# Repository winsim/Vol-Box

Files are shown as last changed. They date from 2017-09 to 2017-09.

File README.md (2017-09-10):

# **Vol-Box**
> A fairly simple project to create a 'USB Volume Control Box' using an Arduino Pro Micro 5v clone and AutoHotKey scripts. As well as integrating my Logitech X-240's original remote controller PCB and the bass control knob from the back of the sub box (such a horrid deisgn..) into the same enclosure as the Arduino.

###### _The Plan:_ 
 centralize ALL audio controls into one small(ish) space on my desk. Including:
   * Main volume control for Logitech X-240 speakers
   * Bass volume control for Logitech X-240 sub woofer
   * Main volume control and mute for computer via USB (done using NicoHood's HID library)
   * Google Chrome volume control and mute via USB (done using AutoHotkey Scripts)
   * Customizable game volume control and mute via USB (done using AutoHotkey Scripts)
   * 3x LEDs to show muted states of rotary encoders
   * Push button to change audio output/source (done using SoundSwitch)
###### _Why:_
   * the lightweight, always in the way or always falling off the back of my desk, often unreachable remote control for my Logitech X-240 speakers really doesn't fit at all into my computer setup and is often pushed off to the back of my desk behind the monitors and the control for the bass is located on the back of the sub box, which is also often pushed to the back of my desk making it very, very difficult to adjust the bass
   * also being as I watch a lot of Netflix and am often forced into changing the volume of whatever I'm watching via the slider given with the player, again this is a hassle.. wouldn't it be great just to have a knob to adjust the volume of Google Chrome within the volume mixer? I think it would! 
   * another problem I'm often faced with is adjusting the volume of fullscreened games.. this can be such a headache! The solution.. a knob to adjust the volume of whatever game (will have a short setup process due to having to change scripts around to your needs) I'm playing at the time within the volume mixer! 
   * sometimes you just have to adjust the master volume within the volume mixer.. soooo.. yet again, ANOTHER KNOB! Plus there's left over pins to play with! 
###### _How:_
   * Finish me! 

### _Overall Schematic:_

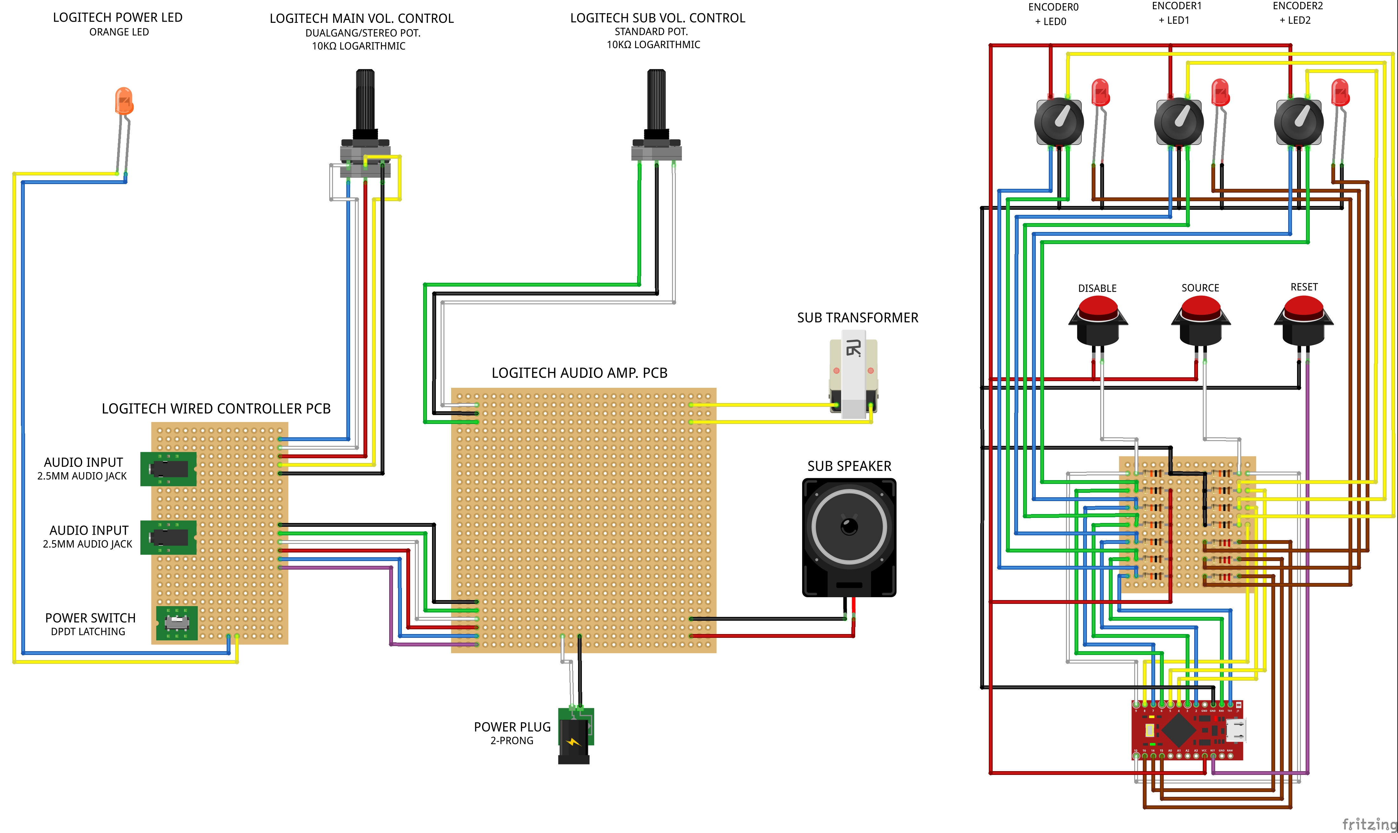
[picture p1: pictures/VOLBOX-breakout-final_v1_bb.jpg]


##### _Part One - Logitech X-240 Rework -_ 
###### _Step One -_ 
  * Remove PCB from inside of sub box
  * Desolder original potentiometer (bass control)
  * Solder 3x 18g wires in place of original potentiometer, secure with hot glue (I ended up using a computer PSU power cable with the                                                                                     ends cut off)
  * Feed wire through back of box and put the PCB back in place
###### _Step Two -_ 
  * Remove PCB from inside of the remote control
  * Desolder original sidewheel potentiometer (speaker volume) **BE CAREFUL! YOU MUST REMEMBER WHICH PINS WENT WHERE!**
  * Desolder original power LED
  * Solder 5x 24g wires in place of original potentiometer, secure with hot glue
  * Solder 2x 24g wires in place of original LED, secure with hot glue
  * Resecure original hot glue joints as they weren't secured very well
  * Cut 2x slots in the bottom of the enclosure to feed the PCB wires through
###### _Step Three -_
  * Drill appropriate holes in front of enclosure 
  * Mount PCB standoffs to controller board and secure to inside of enclosure with hot glue
  * Solder the other ends the 5x 24g wire to a dual-gang (stereo) potentiometer, jump the ground pins together **BE CAREFUL! THE PINOUT                                                                       ON THE BOARD IS REVERSED DUE TO CCW ROTATION TO TURN VOLUME UP!**
  * Solder the other ends of the 2x 24g wire to an orange panel-mount LED
  * Solder the other end of the new cable coming from the back of the sub box to a 10k Ω LOG potentiometer
  * Secure potentiometers and LED to front of enclosure
  * Close up and test out! 
  
###### _Schematic -_

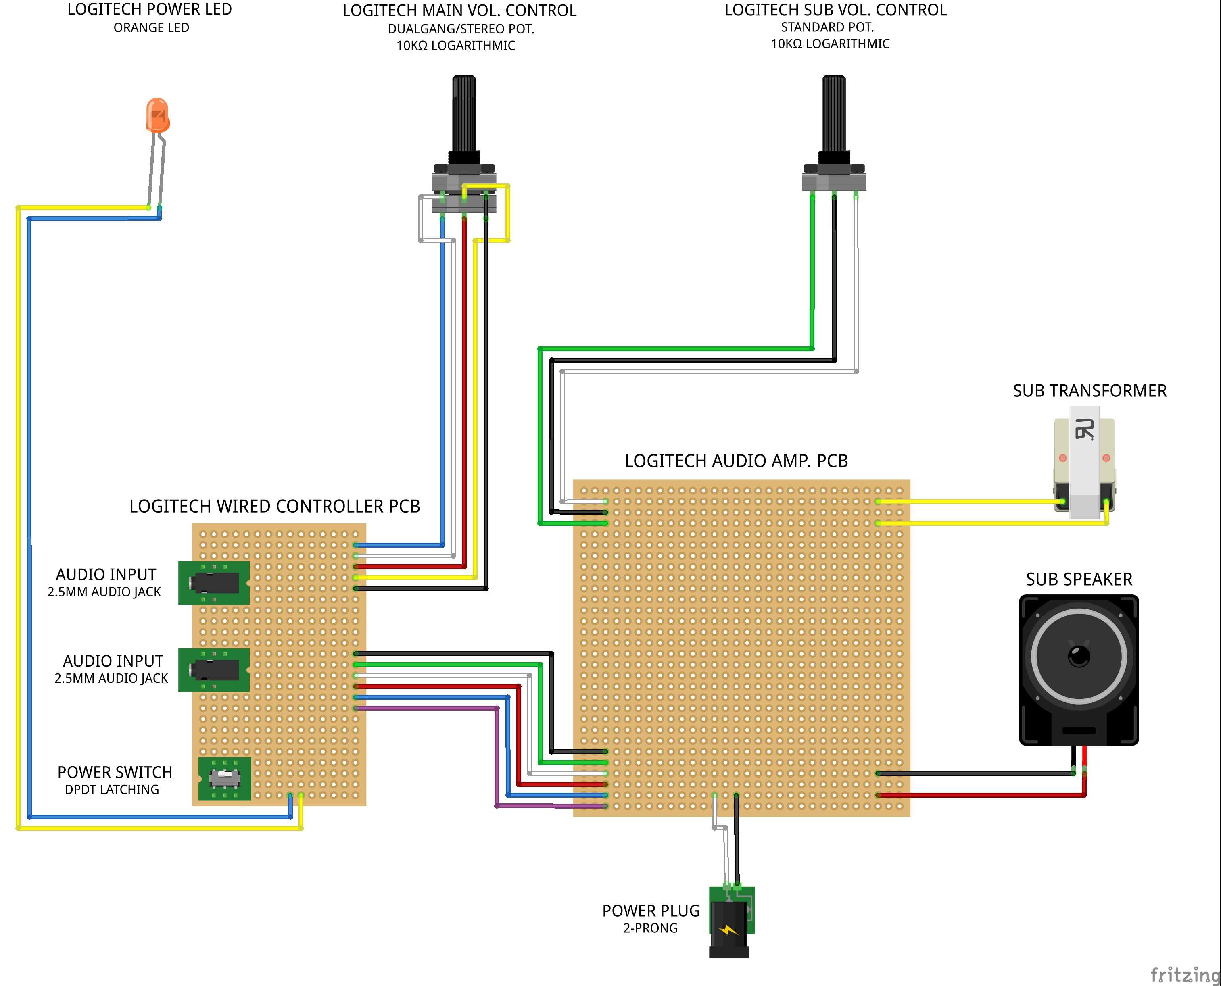
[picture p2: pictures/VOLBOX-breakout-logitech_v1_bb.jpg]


##### _Part Two - Arduino USB Volume Control Project -_
###### _Step One -_
  * Finish me! 

###### _Schematic -_ 

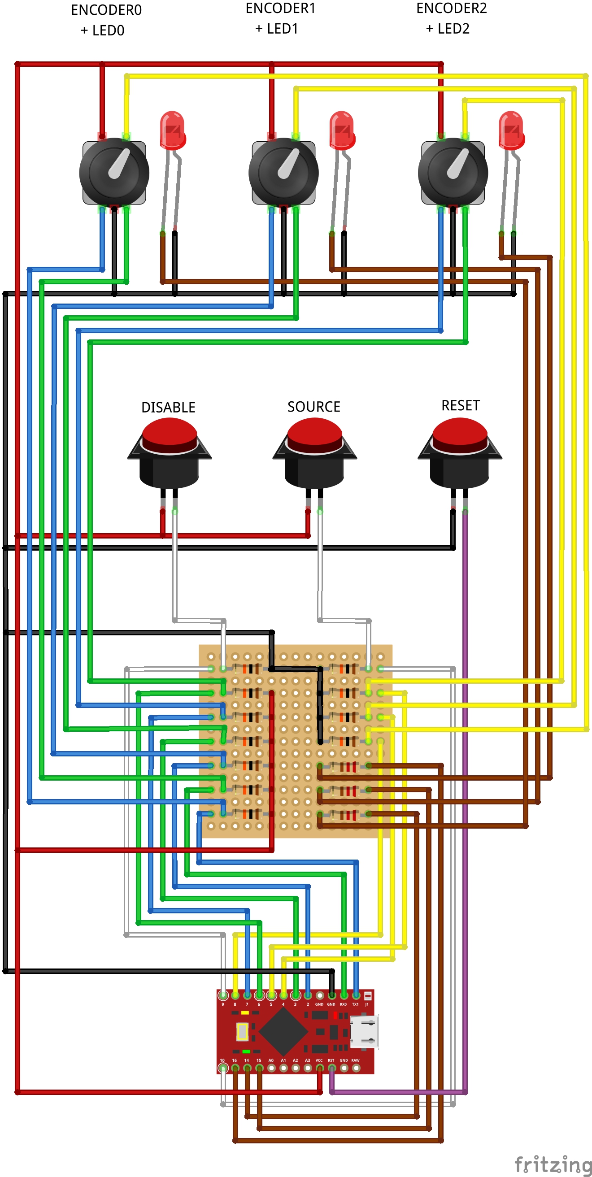
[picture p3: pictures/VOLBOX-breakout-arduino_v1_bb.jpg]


#### _Bill of Materials (for Part One - Logitech X-240 Rework) -_
###### _LEDs -_
   * 1x Orange LED (panel-mount)
###### _Electromechanical -_
   * 1x 10k Ω LOG potentiometer
   * 1x 10k Ω LOG DUAL-GANG (STEREO) potentiometer
###### _Other -_ 
   * 4x PCB standoffs
   * 2x Knobs
   * 1x Enclosure (both the Arduino part and Logitech part will go in the same enclosure)

#### _Bill of Materials (for Part Two - Arduino USB Volume Control Project) -_
###### _Microcontroller -_
   * Arduino Pro Micro (5V, 16MHz)
###### _Resistors -_
   * 10x 10k Ω
   * 3x 220 Ω
###### _LEDs -_
   * 3x Red LEDs (panel-mount)
###### _Electromechanical -_
   * 2x SPST MOM NO push button (1x for Source and 1x for Arduino Reset)
   * 3x Rotary encoders with switches (5-pin)  
###### _Other -_
   * 4x PCB standoffs
   * 3x Knobs
   * 1x Enclosure

#### _Installation -_
###### _Windows:_
1. Download and install the Arduino IDE - (LINK)
2. Download the HID library - (LINK)
3. Copy and paste 'VA.ahk' from included "resources" folder into AutoHotkey's main library folder (default: C:\Users\USER\Documents\AutoHotkey\Lib)
4. Download and install SoundSwitch (optional) - (LINK)

###### _OS X & Linux:_
1. idk..

#### _Arduino Code -_
 Please download the sketch through the repository or through the download page on the wiki. Thanks!

#### _Credits -_
<!-- Markdown link & img dfn's -->
    * loiphin - [loiphin's tech](http://www.loiph.in/2014/09/arduino-leonardo-atmega32u4-based-usb.html/)
    * mrdavidjwatts - [USB-Volume-Control GitHub](https://github.com/mrdavidjwatts/USB-Volume-Control/)
    * alizaliz - [Giant USB Volume Knob](http://www.instructables.com/id/Giant-USB-Volume-Knob/)
    * Lexikos - [VA.ahk](https://github.com/ahkscript/VistaAudio/)

#### _Meta -_

Kyle Gilmour – [@YourTwitter](https://twitter.com/dbader_org) – winsimdevices@gmail.com

Distributed under the MIT license. See ``LICENSE`` for more information.

[https://github.com/winsim/Vol-Box](https://github.com/winsim/Vol-Box/)

<!-- Markdown link & img dfn's -->
[wiki]: https://github.com/winsim/Vol-Box/wiki

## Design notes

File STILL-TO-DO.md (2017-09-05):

# Still to do:

1) Finish README
2) ~Uploaded updated .fzpz files~
    * ~Updated breadboard~
    * ~Updated circuit~
3) Add another INTURRUPT pin
4) Readjust the pinout so...
    * Encoder0 = Main = Top position
    * Encoder1 = Chrome = Middle position
    * Encoder2 = Game = Bottom position
5) Take and upload photos of...
    * Outside of the enclosure...
        - Front
        - Back
        - Bottom
    * Inside of the enclosure...
        - Logitech PCB 
            * Potentiometer rewiring
            * Power switch/LED rewiring
        - Resistor breakout board
        - Arduino
6) Replace the current 'mute state' LEDs; they appear to have burnt out or something, I cannot get them working, even with a voltmeter
    * Ensure that they actually turn on when the corresponding encoder's push button is pressed
7) Correct the button bounce issue
    * Will likey need to include a bounce library
8) Edit the AHK scripts
    * Change suspend to disable
    * Reintroduce mute function to the TOP of all the scripts
9) Fix the SOURCE and DISABLE buttons; currently unplugged inside the box due to button bounce issue
10) Debug the finalized project
11) Carbon vinyl over the face plate
12) Take a video of the working project
    * Upload to YouTube

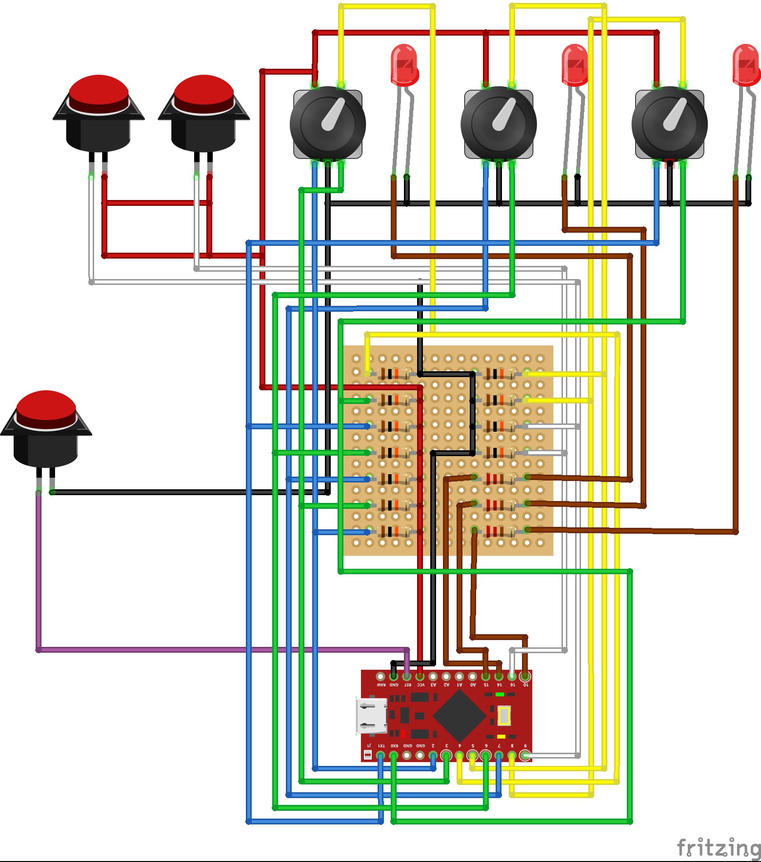
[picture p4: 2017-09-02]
pictures/volbox-bo-3re-v1_bb.jpg

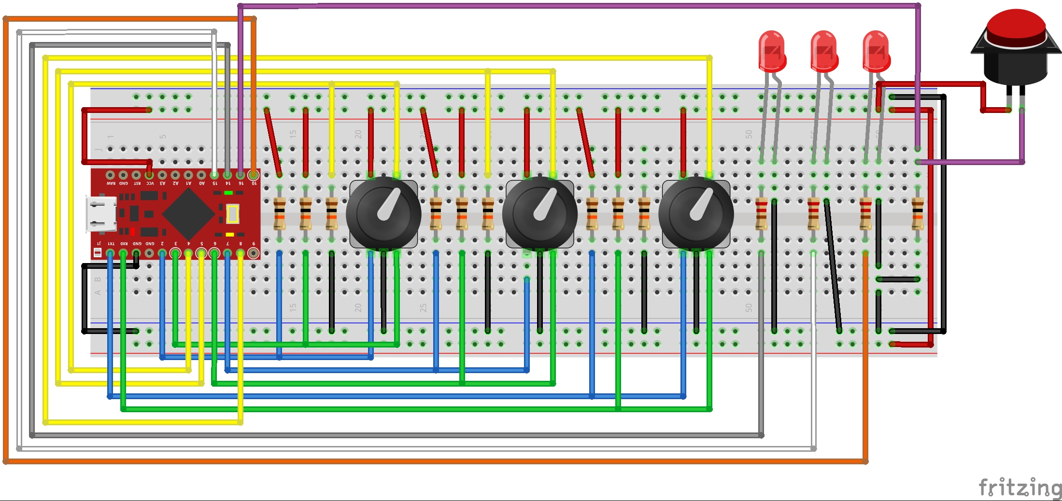
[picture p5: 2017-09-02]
pictures/volbox-bb-3re-v3_bb.jpg

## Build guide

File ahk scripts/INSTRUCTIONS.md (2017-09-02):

## AutoHotkey Instructions:

##### 1) Setup Encoder 1's Script

    i) Right-click 'chrome-vc.ahk' and run it as admin
        - This will make Encoder 1 control Google Chrome
        
    **OR**
    
    ii) Edit 'encoder1-blank.ahk' to fit your needs and run it as admin

##### 2) Setup Encoder 2's Script

    i) Right-click 'dirt_rally-vc.ahk' and run it as admin
        - This will make Encoder 2 control DiRT Rally
        
    **OR**
    
    ii) Edit 'encoder1-blank.ahk' to fit your needs and run it as admin

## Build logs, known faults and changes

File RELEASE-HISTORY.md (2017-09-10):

# _**Release History -**_

* **0.0.8 - Sep 10, 2017**
    * Update: README
    * Add: RELEASE-HISTORY 

* **0.0.7 - Sep 07, 2017**
    * Update: README
    * Completed work on finialized version of enclosure

* **0.0.6 - Sep 05, 2017**
    * Add: 'VOLBOX-breakout-final_v1.fzz' to: '...\fzpz designs'
    * Add: 'VOLBOX-breakout-logitech_v1.fzz' to: '...\fzpz designs'
    * Add: 'VOLBOX-breakout-arduino_v1.fzz' to: '...\fzpz designs'
    * Add: 'VOLBOX-breakout-final_v1_bb.jpg' to: '...\pictures'
    * Add: 'VOLBOX-breakout-logitech_v1_bb.jpg' to: '...\pictures'
    * Add: 'VOLBOX-breakout-arduino_v1_bb.jpg' to: '...\pictures'
    * Did work on finialized version of enclosure
    * Add: STILLTODO
    * Update: README

* **0.0.5 - Sep 03, 2017**
    * Update: README
    
* **0.0.4 - Sep 02, 2017**
    * Add: 'volbox-bo-3re-v1_bb.jpg' to: '...\pictures'
    * Add: '20170902_012336.jpg' to: '...\pictures\mochup-v1'
    * Add: '20170902_012305.jpg' to: '...\pictures\mochup-v1'
    * Add: '20170902_012146.jpg' to: '...\pictures\mochup-v1'

* **0.0.3 - Sep 01, 2017**
    * Update: README
    * Add: Third LED to Arduino Code
    * Add: Third rotary encoder to Arduino Code
    * Add: 'VA.ahk' to: '...\Resources'
    * Add: 'panic-button.ahk', press esc to terminate all running AHK scripts
    * Add: 'chrome-vc.ahk' to: '...\Code\AutoHotKey Scripts'
    * Add: 'dirt_rally-vc.ahk' to: '...\Code\AutoHotKey Scripts'
    * Add: 'dirt_4-vc.ahk' to: '...\Code\AutoHotKey Scripts'
    * Remove: 'chrome-nomute.ahk'
    * Remove: 'dirt_rally-nomute.ahk'
    * Remove: 'dirt_4-nomute.ahk'
    * Add: 'volbox-bo-3re-v3_bb.jpg' to: '...\pictures'
    
* **0.0.2 - Aug 31, 2017**
    * Add: 'chrome-nomute.ahk' to: '...\Code\AutoHotKey Scripts'
    * Add: 'dirt_rally-nomute.ahk' to: '...\Code\AutoHotKey Scripts'
    * Add: 'dirt_4-nomute.ahk' to: '...\Code\AutoHotKey Scripts'
    
* **0.0.1 - Aug 29, 2017**
    * Work in progress

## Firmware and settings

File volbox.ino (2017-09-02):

/*
   A fairly simple project to create a 'USB Volume Control Box' using rotary encoders and an Arduino with the ATmega32U4.
  I used a clone Arduino Pro Micro (Same design as Sparkfun's Pro Micro) but you could also use an Arduino Leonardo or Arduino Micro.
  This project requires the use of rotary encoders, which work in a much different way than a potentiometer. 
  The encoders that I used have a push button as well, this button will be used for muting. 

  Feel free to edit and use this code as you please!   
  - winsim 
*/


#include <Encoder.h>
// The rotary encoder library: https://github.com/PaulStoffregen/Encoder

#include <HID-Project.h>
// The HID library which produces the multimedia keys (Volume UP,DOWN and MUTE):  https://github.com/NicoHood/HID

int accel = 2;
// This is an acceleration factor. Use between 1 and 8 to suit how quickly the volume goes up or down.

const int mute0Pin = 4;
const int mute1Pin = 5;
const int mute2Pin = 8;
// The digital pins to which the rotary encoder push button is connected to. Assumes that the pin has a pull-down resistor.

int LED0 = 14;
int LED1 = 15;
int LED2 = 10;
// The digital pins to which the LEDs are connected to. 

const int buttonSource = 16;
// The digital pin to which the SoundSwitch button is connected to. 

Encoder encoder0(2, 3);
Encoder encoder1(7, 6);
Encoder encoder2(0, 1);
// These are the pins to which the rotary encoder is connected.
// Pins 0,1,2,3,7 are the interrupt pins on a Sparkfun Pro Micro 5V/16MHz, which give best performance with a rotary encoder. 
// Use other pins if you wish, but performance may suffer. Avoid using pins that have LED's attached.

long old0Position  = -999;
long old1Position  = -999;
long old2Position  = -999;
// Variables

int button0State;
int lastButton0State = LOW;
int button1State;
int lastButton1State = LOW;
int button2State;
int lastButton2State = LOW;
int stateSource = 0;
// Input States

long lastDebounceTime = 0;
long debounceDelay = 80;  // Button debounce time in millseconds. Increase if mute button doesnt work properly.
// Debounce

bool downSource = false;

void setup() {
  pinMode(mute0Pin, INPUT);
  pinMode(mute1Pin, INPUT);
  pinMode(mute2Pin, INPUT);
  pinMode(LED0, OUTPUT);
  pinMode(LED1, OUTPUT);
  pinMode(LED2, OUTPUT);
  pinMode(buttonSource, INPUT);
  
  Serial.begin(38400);
  Serial.println("Debug Output:");
  Consumer.begin();
  Keyboard.begin();


// Flash LEDs:
  digitalWrite(LED0, HIGH); delay(200);
  digitalWrite(LED1, HIGH); delay(200);
  digitalWrite(LED2, HIGH); delay(200);
  digitalWrite(LED0, LOW); delay(200);
  digitalWrite(LED1, LOW); delay(200);
  digitalWrite(LED2, LOW); delay(200);
    digitalWrite(LED0, HIGH); delay(200);
    digitalWrite(LED1, HIGH); delay(200);
    digitalWrite(LED2, HIGH); delay(200);
    digitalWrite(LED0, LOW); delay(200);
    digitalWrite(LED1, LOW); delay(200);
    digitalWrite(LED2, LOW); delay(200);
      digitalWrite(LED0, HIGH); delay(200);
      digitalWrite(LED1, HIGH); delay(200);
      digitalWrite(LED2, HIGH); delay(200);
      digitalWrite(LED0, LOW); delay(200);
      digitalWrite(LED1, LOW); delay(200);
      digitalWrite(LED2, LOW); delay(200);
      // Flashes the LEDs three (3) times upon start up
}



void loop() {



//Encoder 0 - MAIN MIXER VOLUME(NO MODIFIER)

  long new0Position = encoder0.read() / accel;
  if (new0Position != old0Position) {
    
    if(new0Position > old0Position) {
      Serial.println("Encoder 0 - MAIN UP");
      Consumer.write(MEDIA_VOLUME_UP);
    }
    
    if(old0Position > new0Position) {
      Serial.println("Encoder 0 - MAIN DOWN");
      Consumer.write(MEDIA_VOLUME_DOWN);
    }
    
    old0Position = new0Position;
    Serial.println(new0Position);
    
  }
  
  // read the state of the switch into a local variable:
  int reading0 = digitalRead(mute0Pin);

  // check to see if you just pressed the button 
  // (i.e. the input went from LOW to HIGH),  and you've waited 
  // long enough since the last press to ignore any noise:  

  // If the switch changed, due to noise or pressing:
  if (reading0 != lastButton0State) {
    // reset the debouncing timer
    lastDebounceTime = millis();
  } 
  
  if ((millis() - lastDebounceTime) > debounceDelay) {
    // whatever the reading is at, it's been there for longer
    // than the debounce delay, so take it as the actual current state:

    // if the button state has changed:
    if (reading0 != button0State) {
      button0State = reading0;
      
      // Toggle MUTE if digital pin reads HIGH
      if (button0State == HIGH) {
        digitalWrite(LED0, HIGH);
        Serial.println("Encoder 0 - MAIN MUTE");
        Consumer.write(MEDIA_VOLUME_MUTE);
      }
    }
  }
  // save the reading.  Next time through the loop,
  // it'll be the lastButtonState:
  
  lastButton0State = reading0;
  digitalWrite(LED0, LOW);
  
  
  
//Encoder 1 - GOOGLE CHROME VOLUME (ALT MODIFIER)

  long new1Position = encoder1.read() / accel;
  if (new1Position != old1Position) {
    
    if(new1Position > old1Position) {
      Serial.println("Encoder 1 - CHROME UP");
         Keyboard.press(HID_KEYBOARD_RIGHT_ALT);
         Keyboard.press(HID_KEYBOARD_F11);
         Keyboard.releaseAll();
    }
    if(old1Position > new1Position) {
      Serial.println("Encoder 1 - CHROME DOWN");
         Keyboard.press(HID_KEYBOARD_RIGHT_ALT);
         Keyboard.press(HID_KEYBOARD_F10);
         Keyboard.releaseAll();
    } 
    old1Position = new1Position;
    Serial.println(new1Position);  
  }
  
  // read the state of the switch into a local variable:
  int reading1 = digitalRead(mute1Pin);

  // check to see if you just pressed the button 
  // (i.e. the input went from LOW to HIGH),  and you've waited 
  // long enough since the last press to ignore any noise:  

  // If the switch changed, due to noise or pressing:
  if (reading1 != lastButton1State) {
    // reset the debouncing timer
    lastDebounceTime = millis();
  } 
  
  if ((millis() - lastDebounceTime) > debounceDelay) {
    // whatever the reading is at, it's been there for longer
    // than the debounce delay, so take it as the actual current state:

    // if the button state has changed:
    if (reading1 != button1State) {
      button1State = reading1;

      // Toggle MUTE if digital pin reads HIGH
      if (button1State == HIGH) {
        digitalWrite(LED1, HIGH);
        Serial.println("Encoder 1 - CHROME MUTE");
         Keyboard.press(HID_KEYBOARD_RIGHT_ALT);
         Keyboard.press(HID_KEYBOARD_F12);
         Keyboard.releaseAll();
      }
    }
  }
  
  // save the reading.  Next time through the loop,
  // it'll be the lastButtonState:
  lastButton1State = reading1;
  digitalWrite(LED1, LOW);



//Encoder 2 - GAME VOLUME (CRTL MODIFIER)

  long new2Position = encoder2.read() / accel;
  if (new2Position != old2Position) {
    
    if(new2Position > old2Position) {
      Serial.println("Encoder 2 - GAME UP");
         Keyboard.press(HID_KEYBOARD_RIGHT_CONTROL);
         Keyboard.press(HID_KEYBOARD_F11);
         Keyboard.releaseAll();
    }
    
    if(old2Position > new2Position) {
      Serial.println("Encoder 2 - GAME DOWN");
         Keyboard.press(HID_KEYBOARD_RIGHT_CONTROL);
         Keyboard.press(HID_KEYBOARD_F10);
         Keyboard.releaseAll();
    }
    
    old2Position = new2Position;
    Serial.println(new2Position);
    
  }
  
  // read the state of the switch into a local variable:
  int reading2 = digitalRead(mute2Pin);

  // check to see if you just pressed the button 
  // (i.e. the input went from LOW to HIGH),  and you've waited 
  // long enough since the last press to ignore any noise:  

  // If the switch changed, due to noise or pressing:
  if (reading2 != lastButton2State) {
    // reset the debouncing timer
    lastDebounceTime = millis();
  } 
  
  if ((millis() - lastDebounceTime) > debounceDelay) {
    // whatever the reading is at, it's been there for longer
    // than the debounce delay, so take it as the actual current state:

    // if the button state has changed:
    if (reading2 != button2State) {
      button2State = reading2;

      // Toggle MUTE if digital pin reads HIGH
      if (button2State == HIGH) {
        digitalWrite(LED2, HIGH);
        Serial.println("Encoder 2 - GAME MUTE");
         Keyboard.press(HID_KEYBOARD_RIGHT_CONTROL);
         Keyboard.press(HID_KEYBOARD_F12);
         Keyboard.releaseAll();
      }
    }
  }
  
  // save the reading.  Next time through the loop,
  // it'll be the lastButtonState:
  lastButton2State = reading2;
  digitalWrite(LED2, LOW);


// Source Button - SOUNDSWAP KEYBIND

  stateSource = digitalRead(buttonSource);

  if(downSource && stateSource == LOW){downSource = false;}

/* Send key combination for Sound Switch application */
   if (!downSource && stateSource == HIGH) { 
      Keyboard.press(HID_KEYBOARD_RIGHT_CONTROL);
      Keyboard.press(HID_KEYBOARD_RIGHT_ALT);
      Keyboard.press(HID_KEYBOARD_F9);
      Keyboard.releaseAll();
      downSource = true; // Only send command once per press
   }
}
